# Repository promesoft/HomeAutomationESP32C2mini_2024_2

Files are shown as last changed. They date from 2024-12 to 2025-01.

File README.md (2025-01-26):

# HomeAutomationESP32C2mini_2024_2

 Kicad 8

# Purpose
Use for build into berker euro dåser

Two PSU modules and two uP modules

Additional power supply for +-12v and 5v for euro rack synth

## PSU
### 1 - Relay and 230V to 5v
### 2 - LED and 230V to 5v
## uP
### 1 - AM2320 and DS18B20
| ESP Designation  | Pin | Use |
| --- | --- | --- |
| U202 ESP32 C3 | GPIO05 | One Wire 18B20 |
| U202 ESP32 C3 | GPIO06 | SDA AM2320 / HDR |
| U202 ESP32 C3 | GPIO07 | SCL AM2320 / HDR |
| U202 ESP32 C3 | GPIO09 | LED |
| U202 ESP32 C3 | GPIO10 | Relay |
| U202 ESP32 C3 | GPIO21 | Relay Alternative |

### 2 - SSD1306 and AHT10
| ESP Designation  | Pin | Use |
| --- | --- | --- |
| U402 ESP32 C3 | GPIO05 | One Wire 18B20 |
| U402 ESP32 C3 | GPIO06 | SDA SSD1306 / AHT10 |
| U402 ESP32 C3 | GPIO07 | SCL SSD1306 / AHT10 |
| U402 ESP32 C3 | GPIO09 | LED |
| U402 ESP32 C3 | GPIO10 | Relay |
| U402 ESP32 C3 | GPIO21 | Relay Alternative |

## PSU for Euro rack - !!!!! EURORACK HEADER FLIPPED !!!!!!
+/-14v and 7v input

2x 16pin Eurorack power connectors as well as a +/-12v,5v,GND connector

Linear regulators 7805,7812,7912

Fuse blown detection with LED indication

# Status - Preliminary mounted
## Initial 
| Stage  | Detail | Status |
| --- | --- | --- |
| create material  | sch/pcb | OK  |
| | gerber | OK |
| production  | | OK |
|  | produced | OK |
|  | delivered | OK? |
## Preliminary validation
| Test  | Detail | Status |
| --- | --- | --- |
| Initial Inspection | PWR RLY | OK |
| Initial Inspection | PWR |  |
| Initial Inspection | ESP32C3 OLED| RELAY not working |
|  | | OLED 0,96" not pin-compatible |
| Initial Inspection | ESP32C3 |  |
| Initial Technical Test | PWR RLY+ESP32C3 OLED AHT10 | OK - Blue LED req 820R - 10K pullup removed as impl in ESP32 pullup |
| Initial Technical Test |  |  |
| Initial Technical Test |  |  |
| Initial Product Test | PWR RLY+ESP32C3 OLED AHT10 | OK |
| Initial Product Test |  |  |
| Initial Product Test |  |  |
| Power Draw |  |  |
| Power Draw |  |  |
| Power Draw |  |  |

## Secondary validation
| Test  | Detail | Status |
| --- | --- |--- |
| Product Test |  | |
| Product Test |  |  |
| Quality | | |
| Quality | | |
| Long Term Product Test |  |  |
| Power Draw |  |  |
| Power Draw |  |  |
| Power Draw |  |  |

## Errata
### Errata - Sub 1
### Errata - Sub 2
### Errata - Eurorack PSU - !!!!! EURORACK HEADER FLIPPED !!!!!!
| ERROR  | Detail | Workaround |
| --- | --- |--- |
| J601 and J602 flipped | -12v on PIN 15+16 - should have been PIN 1+2 | FLIP the header compared to the silkscreen |

## Issues and Notes
### Sub 1
### Sub 2

# Pictures
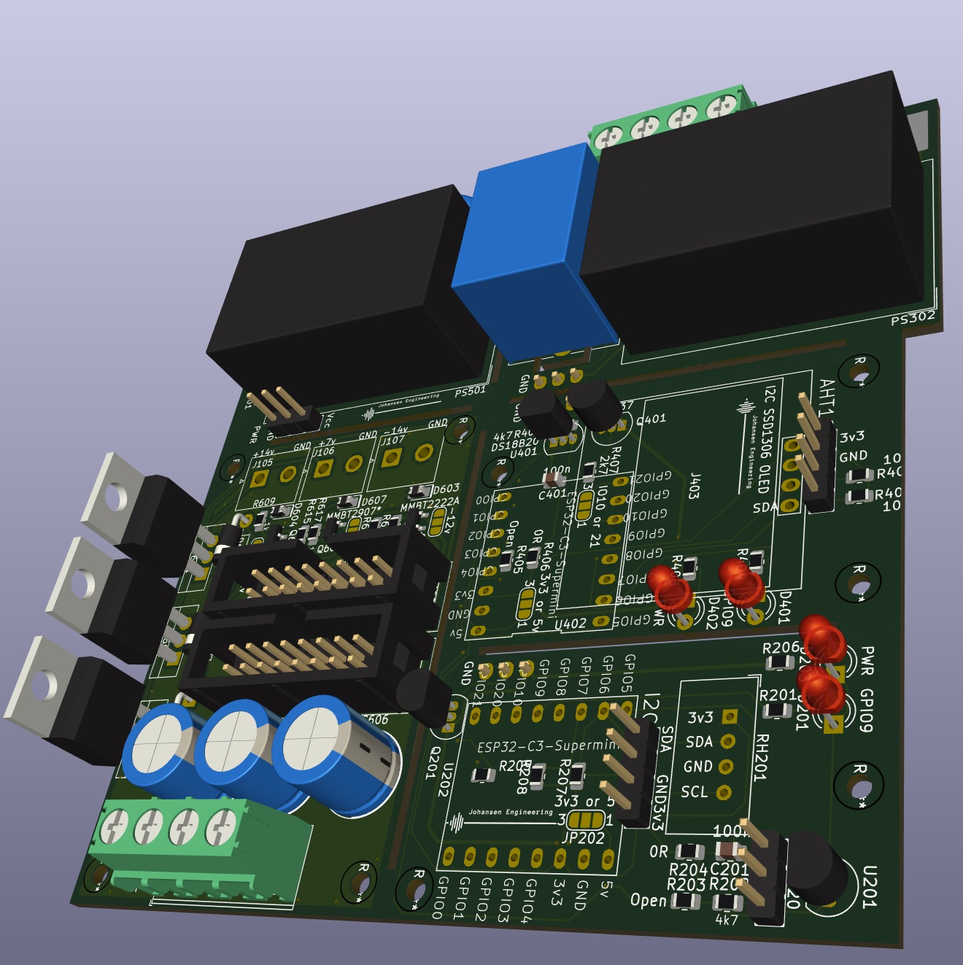
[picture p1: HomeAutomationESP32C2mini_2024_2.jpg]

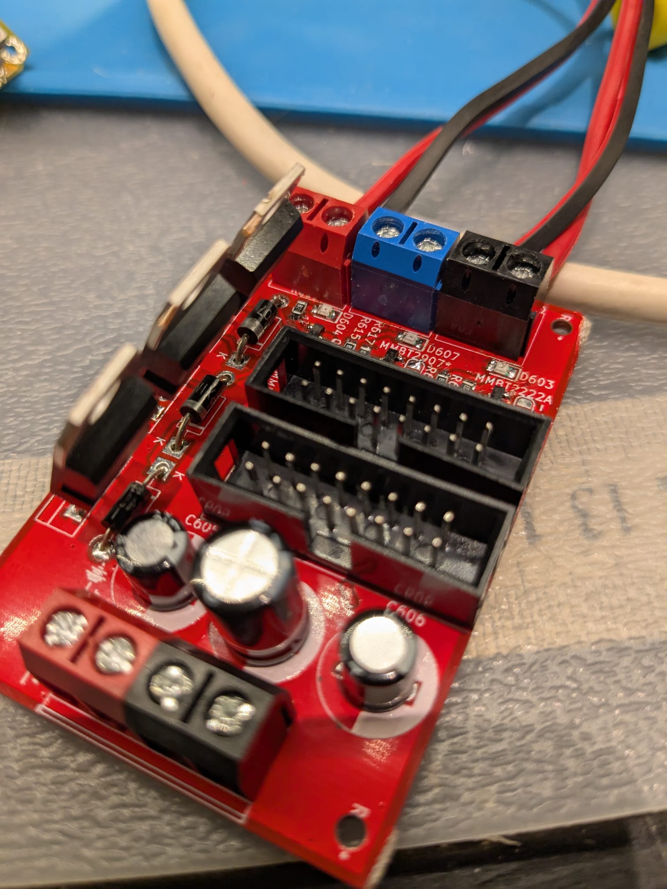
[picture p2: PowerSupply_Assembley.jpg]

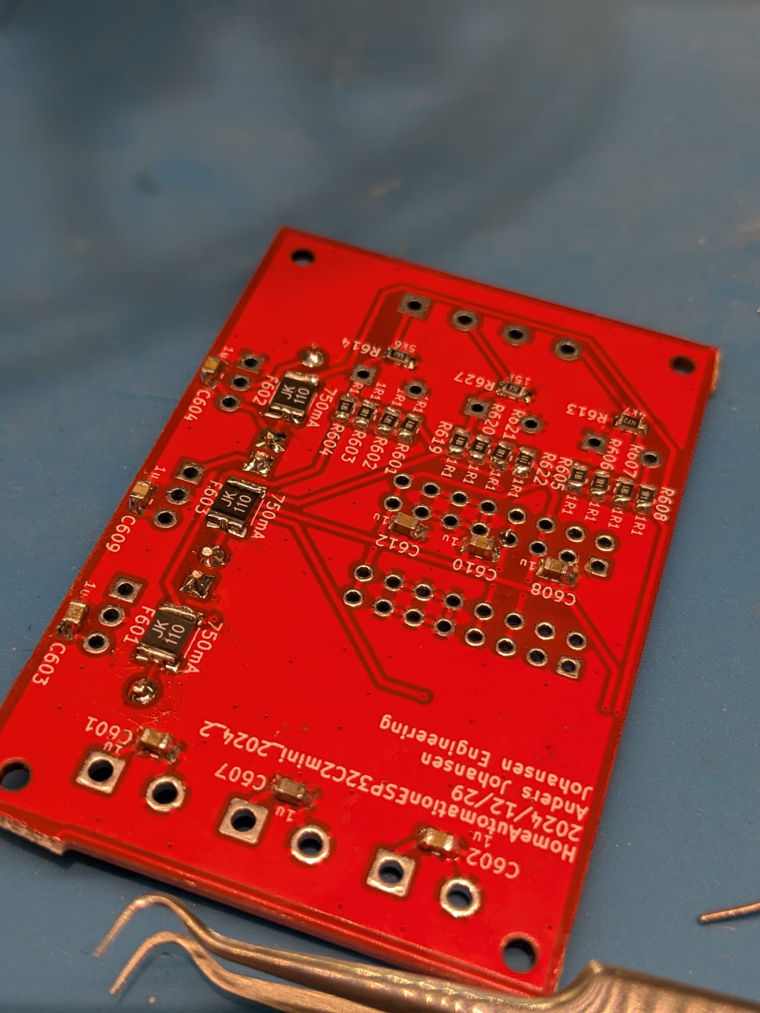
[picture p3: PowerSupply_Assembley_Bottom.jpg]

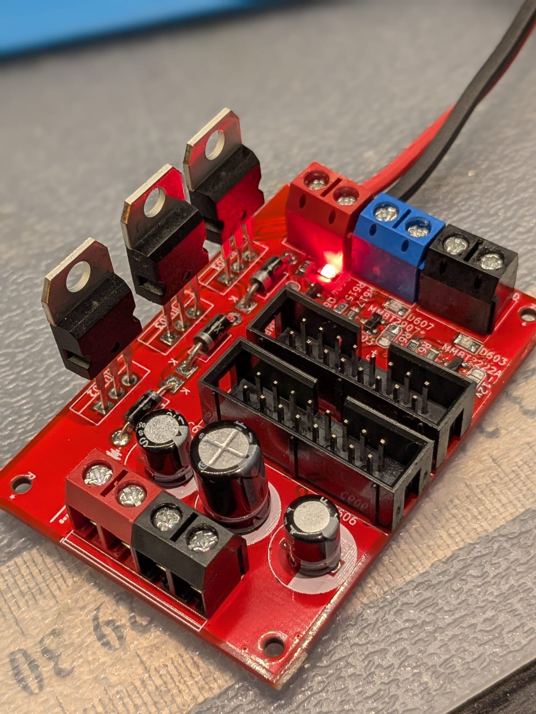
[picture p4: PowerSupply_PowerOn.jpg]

![]()
![]()

# Inspiration
https://github.com/pforrmi/KiCad-SSD1306-128x64/tree/master

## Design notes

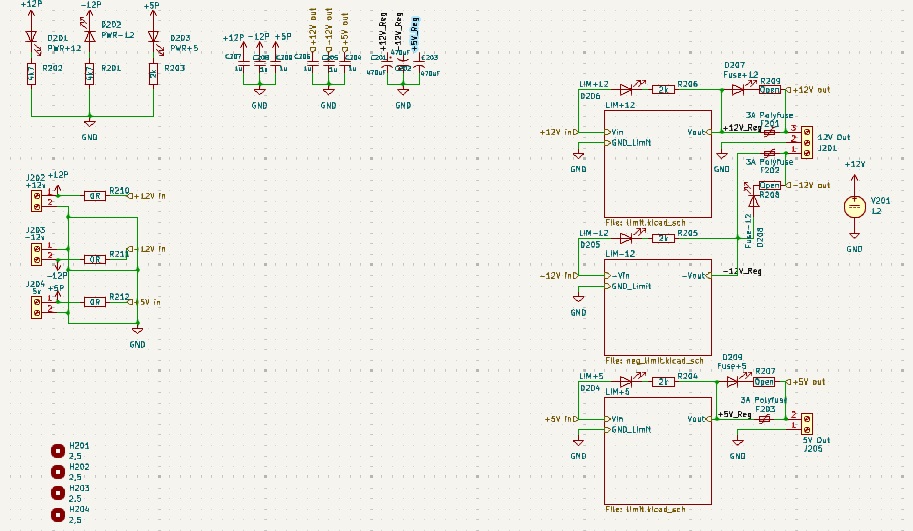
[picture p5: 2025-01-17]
Filter_sch_1.jpg

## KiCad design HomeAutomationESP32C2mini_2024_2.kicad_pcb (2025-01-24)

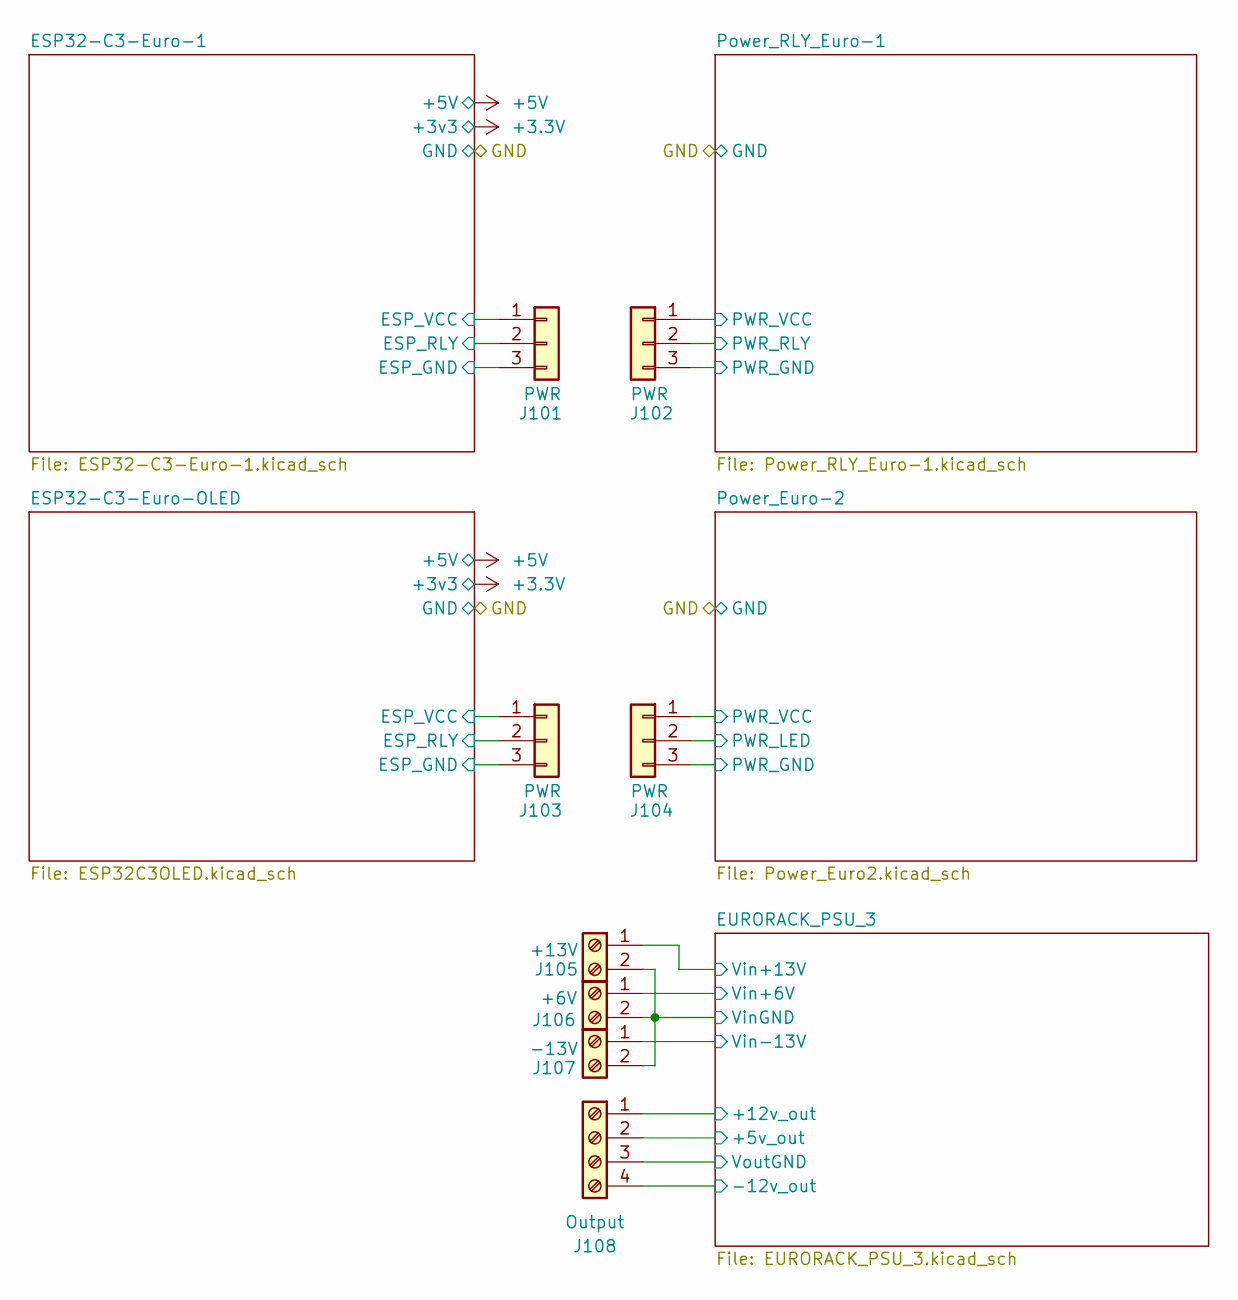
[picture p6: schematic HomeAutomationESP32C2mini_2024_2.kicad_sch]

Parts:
J101, J102, J103, J104: PWR; Pins_1x03_2.54mm_TH; Part Number 1-0301FBV0T
J105: +13V; JST_NV_B02P-NV_1x02_P5.00mm_Vertical
J106: +6V; JST_NV_B02P-NV_1x02_P5.00mm_Vertical
J107: -13V; JST_NV_B02P-NV_1x02_P5.00mm_Vertical
J108: Output; TerminalBlock_Phoenix_PT-1,5-4-5.0-H_1x04_P5.00mm_Horizontal

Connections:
/ESP32-C3-Euro-1/ESP_RLY: J101.2; also elsewhere on the board
/ESP32-C3-Euro-1/ESP_VCC: J101.1; also elsewhere on the board
/ESP32-C3-Euro-OLED/ESP_RLY: J103.2; also elsewhere on the board
/ESP32-C3-Euro-OLED/ESP_VCC: J103.1; also elsewhere on the board
/EURORACK_PSU_3/-12v_out: J108.4; also elsewhere on the board
/EURORACK_PSU_3/Vin+6V: J106.1; also elsewhere on the board
/EURORACK_PSU_3/Vin+13V: J105.1; also elsewhere on the board
/EURORACK_PSU_3/Vin-13V: J107.1; also elsewhere on the board
/GND: J101.3, J103.3, J104.3; also elsewhere on the board
/Power_Euro-2/PWR_LED: J104.2; also elsewhere on the board
/Power_Euro-2/PWR_VCC: J104.1; also elsewhere on the board
/Power_RLY_Euro-1/PWR_GND: J102.3; also elsewhere on the board
/Power_RLY_Euro-1/PWR_RLY: J102.2; also elsewhere on the board
/Power_RLY_Euro-1/PWR_VCC: J102.1; also elsewhere on the board

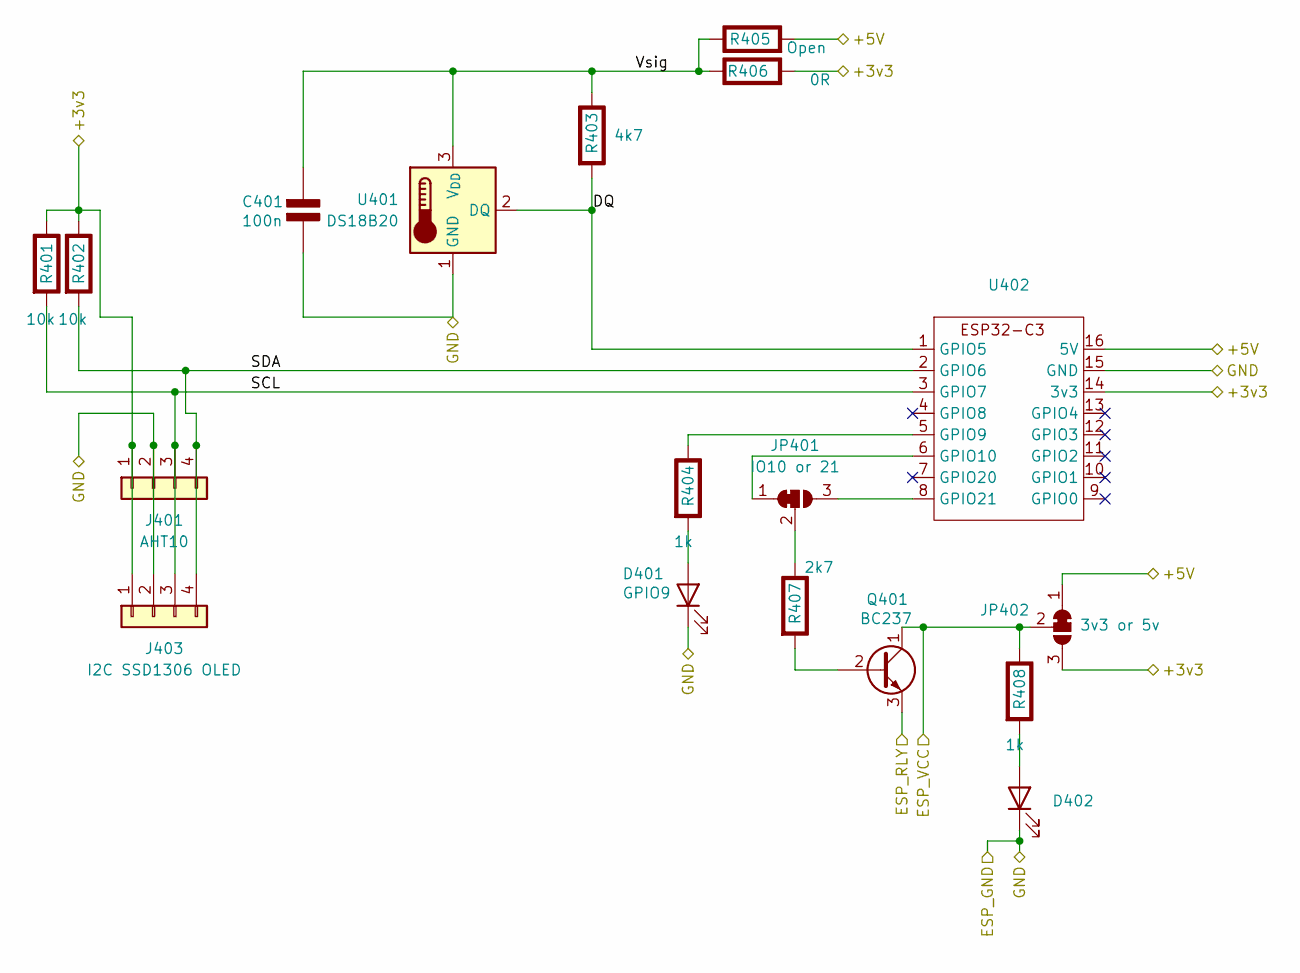
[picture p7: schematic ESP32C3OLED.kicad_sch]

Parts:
C401: 100n; C_0805_2012Metric; Rating V
D401: GPIO9; LED_D3.0mm
D402: PWR; LED_D3.0mm
J401: AHT10; Pins_1x04_2.54mm_TH
J403: I2C SSD1306 OLED; 128x64OLED
JP401: IO10 or 21; SolderJumper-3_P1.3mm_Bridged12_RoundedPad1.0x1.5mm_NumberL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
JP402: 3v3 or 5v; SolderJumper-3_P1.3mm_Bridged12_RoundedPad1.0x1.5mm_NumberL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
Q401: BC237; TO-92_Inline
R401, R402: 10k; R_0805_2012Metric; Rating W
R403: 4k7; R_0805_2012Metric; Rating W
R404, R408: 1k; R_0805_2012Metric; Rating W
R405: Open; R_0805_2012Metric; Rating W
R406: 0R; R_0805_2012Metric; Rating W
R407: 2k7; R_0805_2012Metric; Rating W
U401: DS18B20; TO-92_Inline
U402: ESP32-C3-Supermini

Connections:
+3.3V: J401.1, J403.1, JP402.3 (B), R401.1 (+), R402.1 (+), R406.2 (-), U402.14 (3v3); also elsewhere on the board
+5V: JP402.1 (A), R405.2 (-), U402.16 (5V); also elsewhere on the board
/ESP32-C3-Euro-OLED/DQ: R403.2 (-), U401.2 (DQ), U402.1 (GPIO5)
/ESP32-C3-Euro-OLED/ESP_RLY: Q401.3 (E); also elsewhere on the board
/ESP32-C3-Euro-OLED/ESP_VCC: JP402.2 (C), Q401.1 (C), R408.1 (+); also elsewhere on the board
/ESP32-C3-Euro-OLED/SCL: J401.3, J403.3, R401.2 (-), U402.3 (GPIO7)
/ESP32-C3-Euro-OLED/SDA: J401.4, J403.4, R402.2 (-), U402.2 (GPIO6)
/ESP32-C3-Euro-OLED/Vsig: C401.1 (+), R403.1 (+), R405.1 (+), R406.1 (+), U401.3 (V_{DD})
/GND: C401.2 (-), D401.1 (K), D402.1 (K), J401.2, J403.2, U401.1 (GND), U402.15 (GND); also elsewhere on the board
unnamed: D401.2 (A), R404.2 (-)
unnamed: D402.2 (A), R408.2 (-)
unnamed: JP401.1 (A), U402.6 (GPIO10)
unnamed: JP401.3 (B), U402.8 (GPIO21)
unnamed: JP401.2 (C), R407.1 (+)
unnamed: Q401.2 (B), R407.2 (-)
unnamed: R404.1 (+), U402.5 (GPIO9)

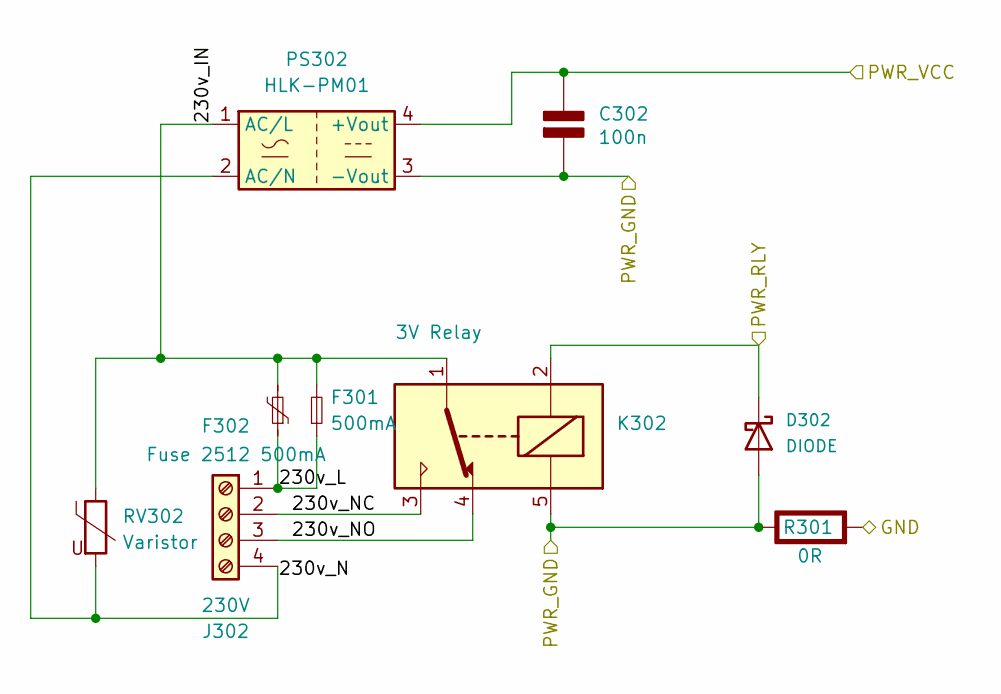
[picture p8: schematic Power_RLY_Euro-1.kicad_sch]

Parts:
C302: 100n; C_0805_2012Metric; Rating V
D302: DIODE; D_DO-41_SOD81_P10.16mm_Horizontal
F301: 500mA; Fuse_Littelfuse-NANO2-462
F302: Fuse 2512 500mA; Fuse_2512_6332Metric_Pad1.52x3.35mm_HandSolder
J302: 230V; TerminalBlock_Phoenix_PT-1,5-4-5.0-H_1x04_P5.00mm_Horizontal
K302: 3V Relay; Relay_SPDT_SANYOU_SRD_Series_Form_C
PS302: HLK-PM01; Converter_ACDC_Hi-Link_HLK-PMxx
R301: 0R; R_0805_2012Metric; Rating W
RV302: Varistor; RV_Disc_D9mm_W4.8mm_P5mm

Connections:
/GND: R301.2 (-); also elsewhere on the board
/Power_RLY_Euro-1/230v_IN: F301.2, F302.2, K302.1, PS302.1 (AC/L), RV302.1
/Power_RLY_Euro-1/230v_L: F301.1, F302.1, J302.1
/Power_RLY_Euro-1/230v_N: J302.4, PS302.2 (AC/N), RV302.2
/Power_RLY_Euro-1/230v_NC: J302.2, K302.3
/Power_RLY_Euro-1/230v_NO: J302.3, K302.4
/Power_RLY_Euro-1/PWR_GND: C302.2 (-), D302.2 (A), K302.5, PS302.3 (-Vout), R301.1 (+); also elsewhere on the board
/Power_RLY_Euro-1/PWR_RLY: D302.1 (K), K302.2; also elsewhere on the board
/Power_RLY_Euro-1/PWR_VCC: C302.1 (+), PS302.4 (+Vout); also elsewhere on the board

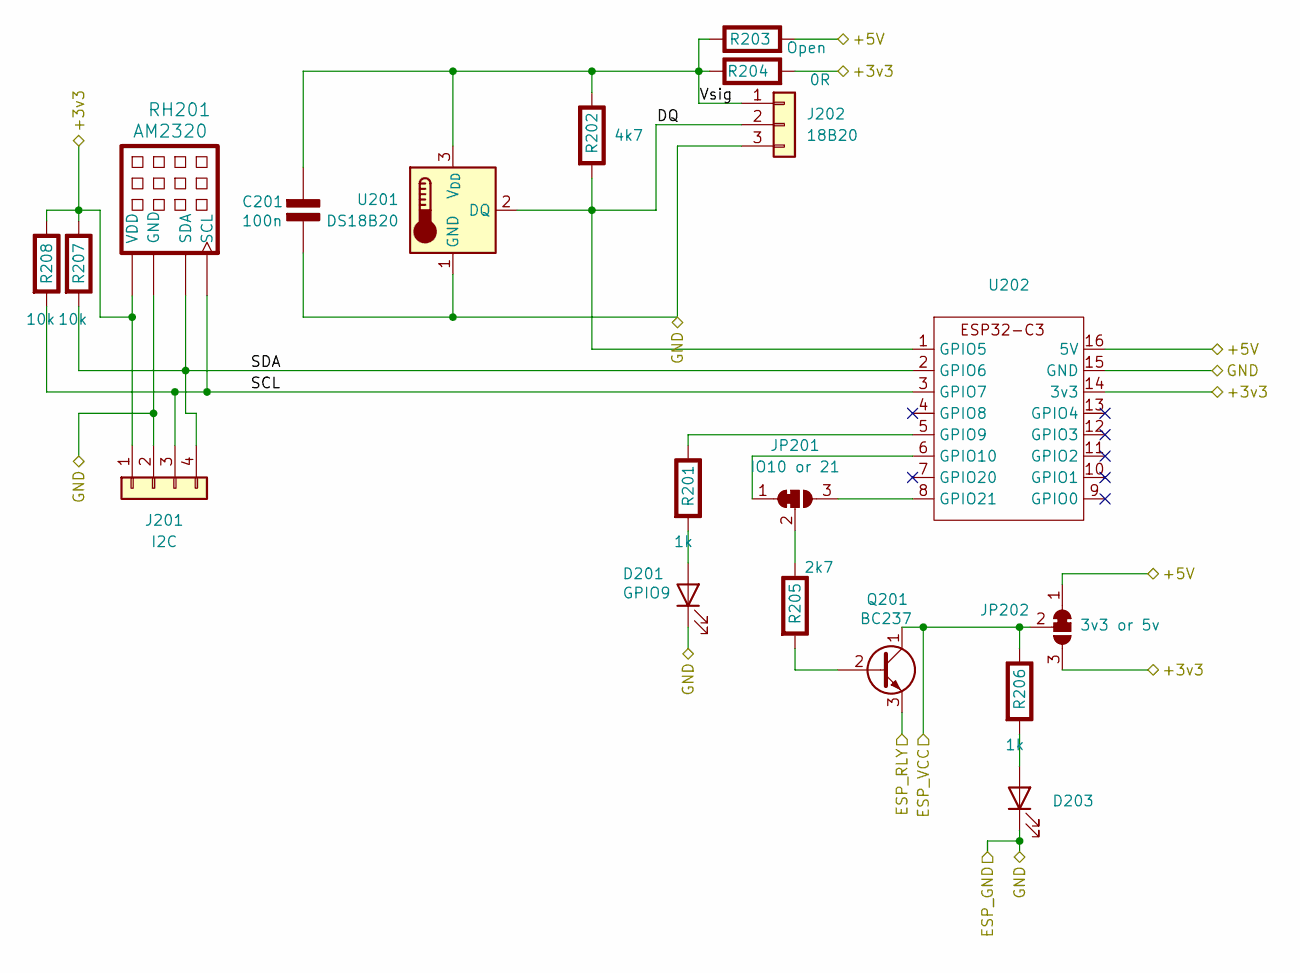
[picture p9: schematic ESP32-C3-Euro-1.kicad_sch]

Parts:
C201: 100n; C_0805_2012Metric; Rating V
D201: GPIO9; LED_D3.0mm
D203: PWR; LED_D3.0mm
J201: I2C; Pins_1x04_2.54mm_TH
J202: 18B20; Pins_1x03_2.54mm_TH; Part Number 1-0301FBV0T
JP201: IO10 or 21; SolderJumper-3_P1.3mm_Bridged12_RoundedPad1.0x1.5mm_NumberL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
JP202: 3v3 or 5v; SolderJumper-3_P1.3mm_Bridged12_RoundedPad1.0x1.5mm_NumberL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
Q201: BC237; TO-92_Inline
R201, R206: 1k; R_0805_2012Metric; Rating W
R202: 4k7; R_0805_2012Metric; Rating W
R203: Open; R_0805_2012Metric; Rating W
R204: 0R; R_0805_2012Metric; Rating W
R205: 2k7; R_0805_2012Metric; Rating W
R207, R208: 10k; R_0805_2012Metric; Rating W
RH201: AM2320; ASAIR_AM2302_P2.54mm_Vertical
U201: DS18B20; TO-92_Inline
U202: ESP32-C3-Supermini

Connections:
+3.3V: J201.1, JP202.3 (B), R204.2 (-), R207.1 (+), R208.1 (+), RH201.1 (VDD), U202.14 (3v3); also elsewhere on the board
+5V: JP202.1 (A), R203.2 (-), U202.16 (5V); also elsewhere on the board
/ESP32-C3-Euro-1/DQ: J202.2, R202.2 (-), U201.2 (DQ), U202.1 (GPIO5)
/ESP32-C3-Euro-1/ESP_RLY: Q201.3 (E); also elsewhere on the board
/ESP32-C3-Euro-1/ESP_VCC: JP202.2 (C), Q201.1 (C), R206.1 (+); also elsewhere on the board
/ESP32-C3-Euro-1/SCL: J201.3, R208.2 (-), RH201.4 (SCL), U202.3 (GPIO7)
/ESP32-C3-Euro-1/SDA: J201.4, R207.2 (-), RH201.2 (SDA), U202.2 (GPIO6)
/ESP32-C3-Euro-1/Vsig: C201.1 (+), J202.1, R202.1 (+), R203.1 (+), R204.1 (+), U201.3 (V_{DD})
/GND: C201.2 (-), D201.1 (K), D203.1 (K), J201.2, J202.3, RH201.3 (GND), U201.1 (GND), U202.15 (GND); also elsewhere on the board
unnamed: D201.2 (A), R201.2 (-)
unnamed: D203.2 (A), R206.2 (-)
unnamed: JP201.1 (A), U202.6 (GPIO10)
unnamed: JP201.3 (B), U202.8 (GPIO21)
unnamed: JP201.2 (C), R205.1 (+)
unnamed: Q201.2 (B), R205.2 (-)
unnamed: R201.1 (+), U202.5 (GPIO9)

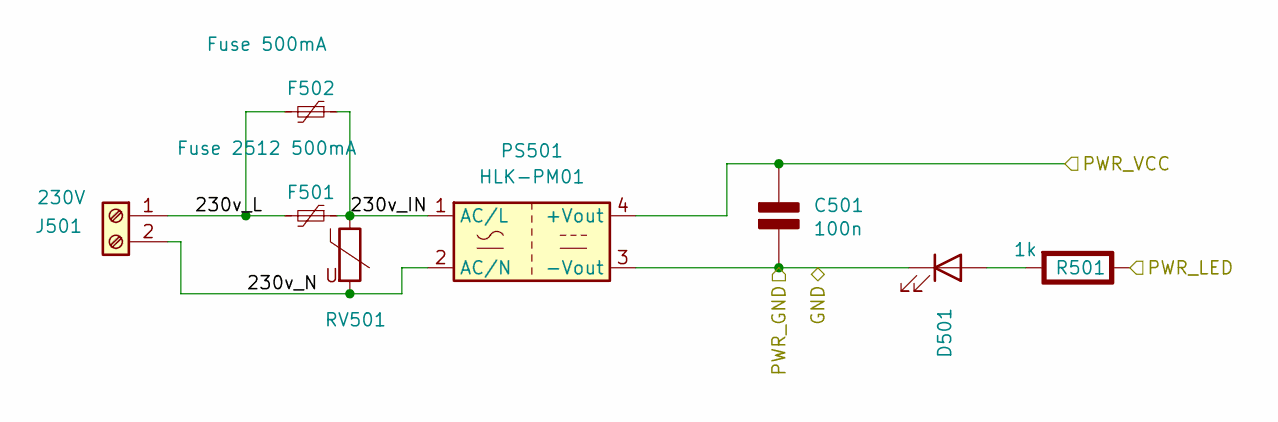
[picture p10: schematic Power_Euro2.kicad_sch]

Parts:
C501: 100n; C_0805_2012Metric; Rating V
D501: PWR; LED_0805_2012Metric_Pad1.15x1.40mm_HandSolder
F501: Fuse 2512 500mA; Fuse_2512_6332Metric_Pad1.52x3.35mm_HandSolder
F502: Fuse 500mA; L_Axial_L7.0mm_D3.3mm_P5.08mm_Vertical_Fastron_MICC
J501: 230V; JST_NV_B02P-NV_1x02_P5.00mm_Vertical
PS501: HLK-PM01; Converter_ACDC_Hi-Link_HLK-PMxx
R501: 1k; R_0805_2012Metric; Rating W
RV501: Varistor; RV_Disc_D9mm_W4.8mm_P5mm

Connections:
/GND: C501.2 (-), D501.1 (K), PS501.3 (-Vout); also elsewhere on the board
/Power_Euro-2/230v_IN: F501.1, F502.1, PS501.1 (AC/L), RV501.1
/Power_Euro-2/230v_L: F501.2, F502.2, J501.1
/Power_Euro-2/230v_N: J501.2, PS501.2 (AC/N), RV501.2
/Power_Euro-2/PWR_LED: R501.1 (+); also elsewhere on the board
/Power_Euro-2/PWR_VCC: C501.1 (+), PS501.4 (+Vout); also elsewhere on the board
unnamed: D501.2 (A), R501.2 (-)

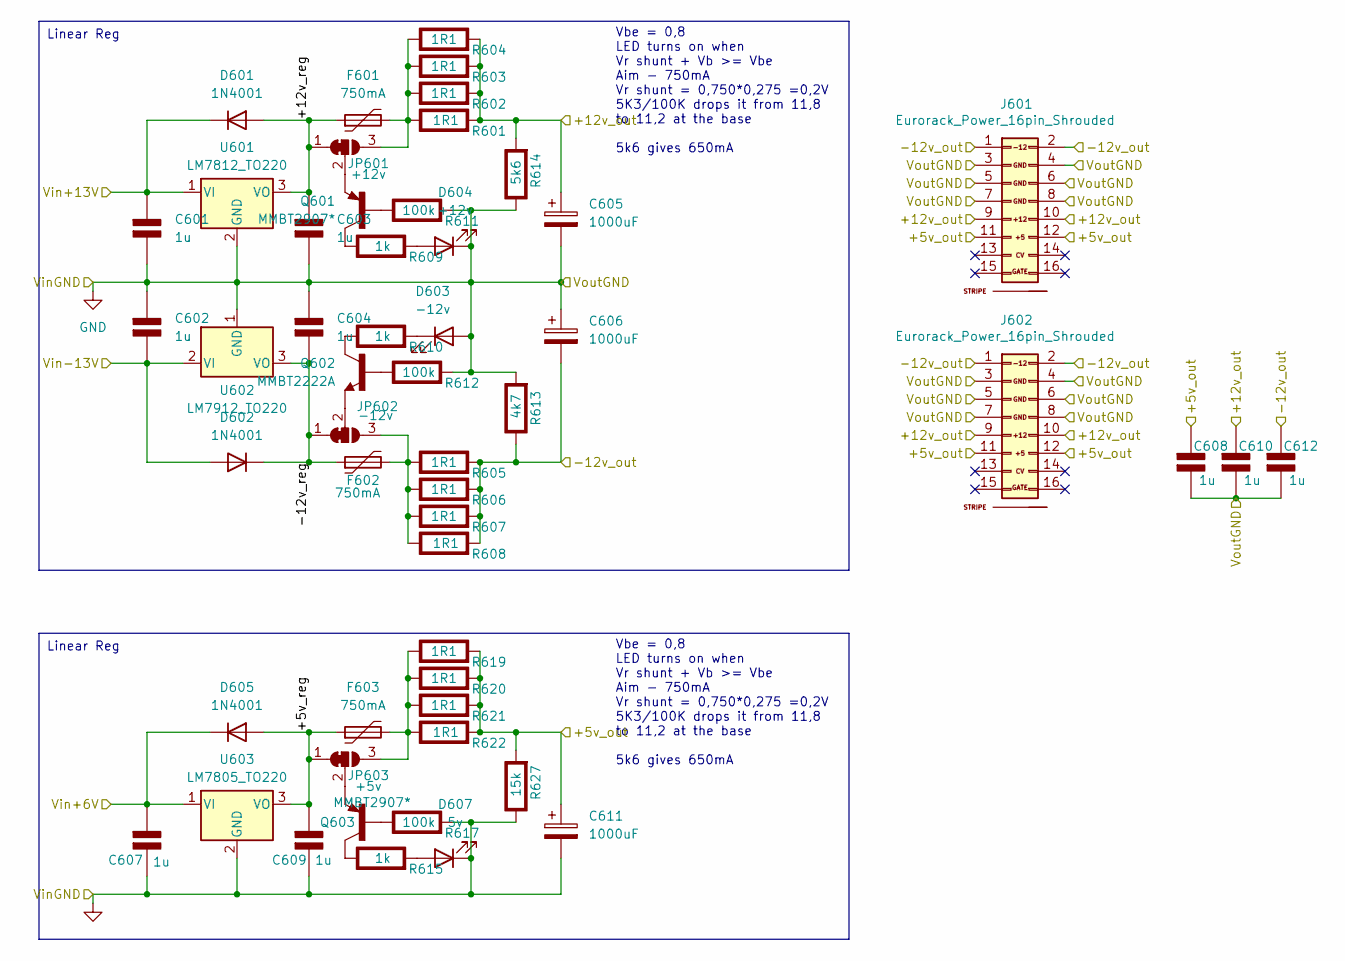
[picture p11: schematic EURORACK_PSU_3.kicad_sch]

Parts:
C601, C602, C603, C604, C607, C608, C609, C610, C612: 1u; C_0805_AJ; Rating V
C605, C606, C611: 1000uF; CP_Radial_D10.0mm_P5.00mm
D601, D602, D605: 1N4001; D_DO-41_SOD81_P10.16mm_Horizontal
D603: -12v; D_0805_AJ
D604: +12v; D_0805_AJ
D607: 5v; D_0805_AJ
F601, F602, F603: 750mA; Fuse_1812_4532Metric
J601, J602: Eurorack_Power_16pin_Shrouded; IDC-Header_2x08_P2.54mm_Vertical; Part Number LL1007-1 (2*8 HITEMP)
JP601: +12v; SolderJumper-3_P1.3mm_Bridged12_RoundedPad1.0x1.5mm_NumberL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
JP602: -12v; SolderJumper-3_P1.3mm_Bridged12_RoundedPad1.0x1.5mm_NumberL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
JP603: +5v; SolderJumper-3_P1.3mm_Bridged12_RoundedPad1.0x1.5mm_NumberL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
Q601, Q603: MMBT2907*; SOT-23
Q602: MMBT2222A; SOT-23
R601, R602, R603, R604, R605, R606, R607, R608, R619, R620, R621, R622: 1R1; R_0805_AJ; Rating W
R609, R610, R615: 1k; R_0805_AJ; Rating W
R611, R612, R617: 100k; R_0805_AJ; Rating W
R613: 4k7; R_0805_AJ; Rating W
R614: 5k6; R_0805_AJ; Rating W
R627: 15k; R_0805_AJ; Rating W
U601: LM7812_TO220; TO-220-3_Vertical
U602: LM7912_TO220; TO-220-3_Vertical
U603: LM7805_TO220; TO-220-3_Vertical

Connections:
/EURORACK_PSU_3/+5v_reg: C609.1 (+), D605.2 (A), F603.1, JP603.1 (A), U603.3 (VO)
/EURORACK_PSU_3/+12v_reg: C603.1 (+), D601.2 (A), F601.1, JP601.1 (A), U601.3 (VO)
/EURORACK_PSU_3/-12v_out: C606.2, C612.1 (+), J601.1, J601.2, J601.15 (-12V), J601.16, J602.1, J602.2, J602.15 (-12V), J602.16, R605.2 (-), R606.2 (-), R607.2 (-), R608.2 (-), R613.1 (+); also elsewhere on the board
/EURORACK_PSU_3/-12v_reg: C604.2 (-), D602.1 (K), F602.1, JP602.1 (A), U602.3 (VO)
/EURORACK_PSU_3/Vin+6V: C607.1 (+), D605.1 (K), U603.1 (VI); also elsewhere on the board
/EURORACK_PSU_3/Vin+13V: C601.1 (+), D601.1 (K), U601.1 (VI); also elsewhere on the board
/EURORACK_PSU_3/Vin-13V: C602.2 (-), D602.2 (A), U602.2 (VI); also elsewhere on the board
unnamed: D603.1 (K), R610.2 (-)
unnamed: D604.2 (A), R609.2 (-)
unnamed: D607.2 (A), R615.2 (-)
unnamed: F601.2, JP601.3 (B), R601.1 (+), R602.1 (+), R603.1 (+), R604.1 (+)
unnamed: JP601.2 (C), Q601.2 (E)
unnamed: F602.2, JP602.3 (B), R605.1 (+), R606.1 (+), R607.1 (+), R608.1 (+)
unnamed: JP602.2 (C), Q602.2 (E)
unnamed: F603.2, JP603.3 (B), R619.1 (+), R620.1 (+), R621.1 (+), R622.1 (+)
unnamed: JP603.2 (C), Q603.2 (E)
unnamed: Q601.1 (B), R611.1 (+)
unnamed: Q601.3 (C), R609.1 (+)
unnamed: Q602.1 (B), R612.1 (+)
unnamed: Q602.3 (C), R610.1 (+)
unnamed: Q603.1 (B), R617.1 (+)
unnamed: Q603.3 (C), R615.1 (+)

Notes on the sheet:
Linear Reg
Vbe = 0,8 LED turns on when Vr shunt + Vb >= Vbe Aim - 750mA Vr shunt = 0,750*0,275 =0,2V 5K3/100K drops it from 11,8 to 11,2 at the base 5k6 gives 650mA

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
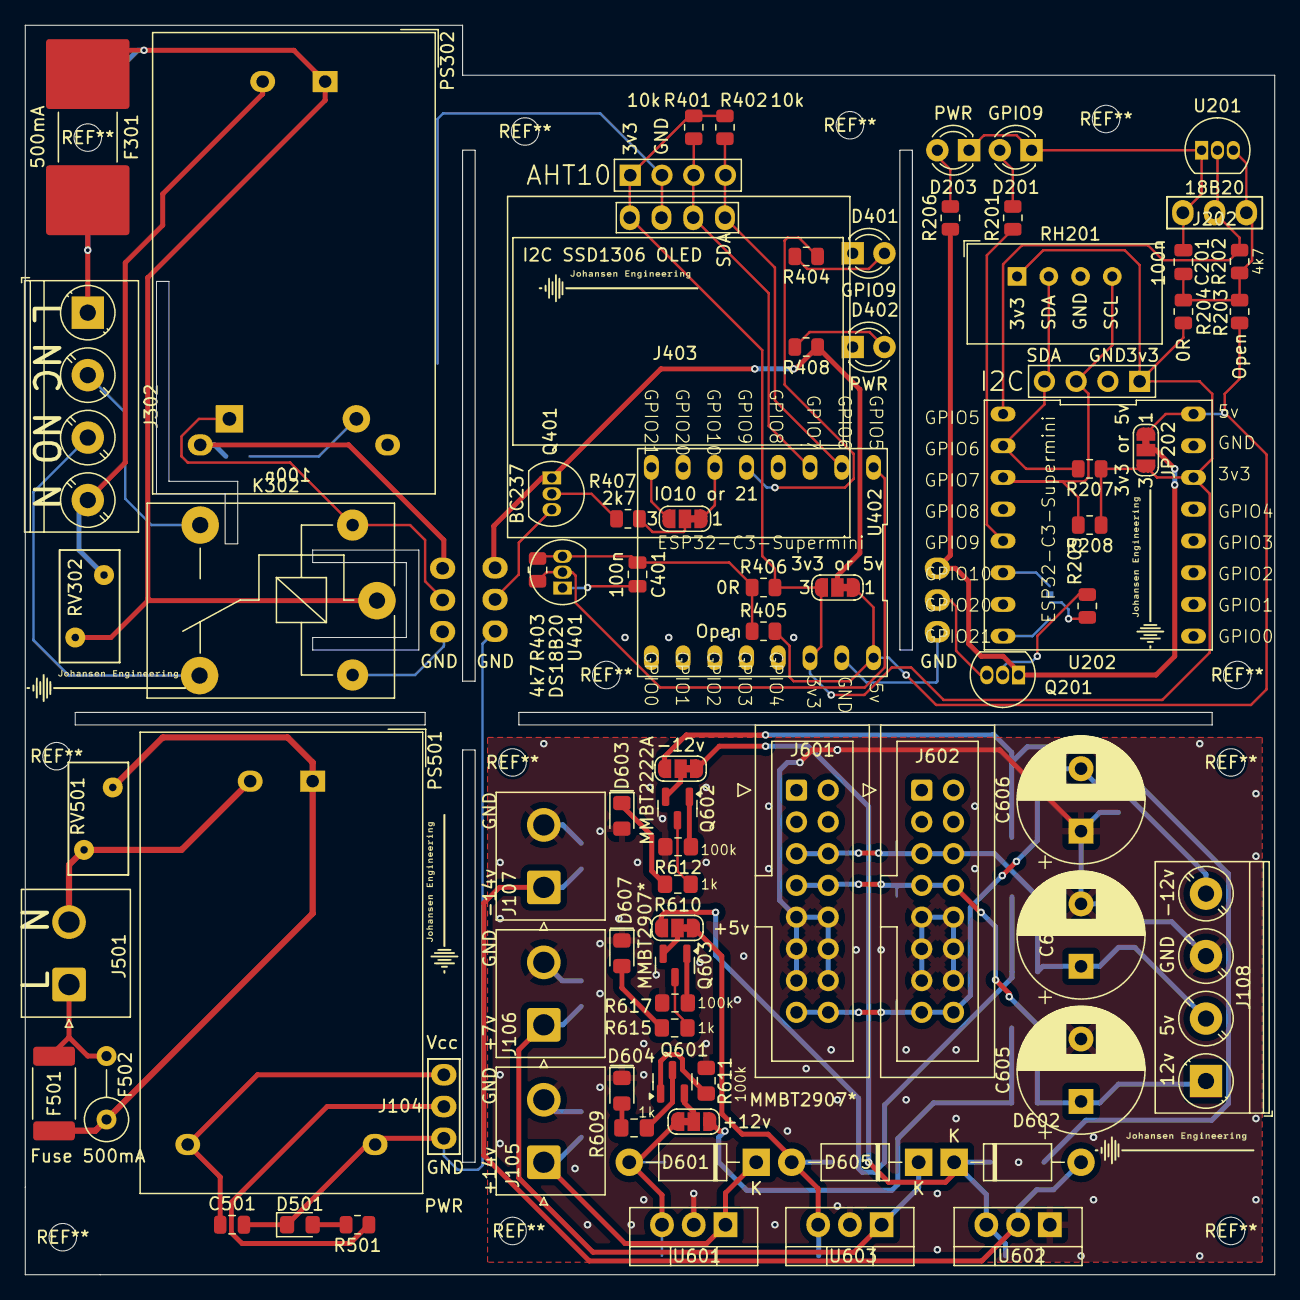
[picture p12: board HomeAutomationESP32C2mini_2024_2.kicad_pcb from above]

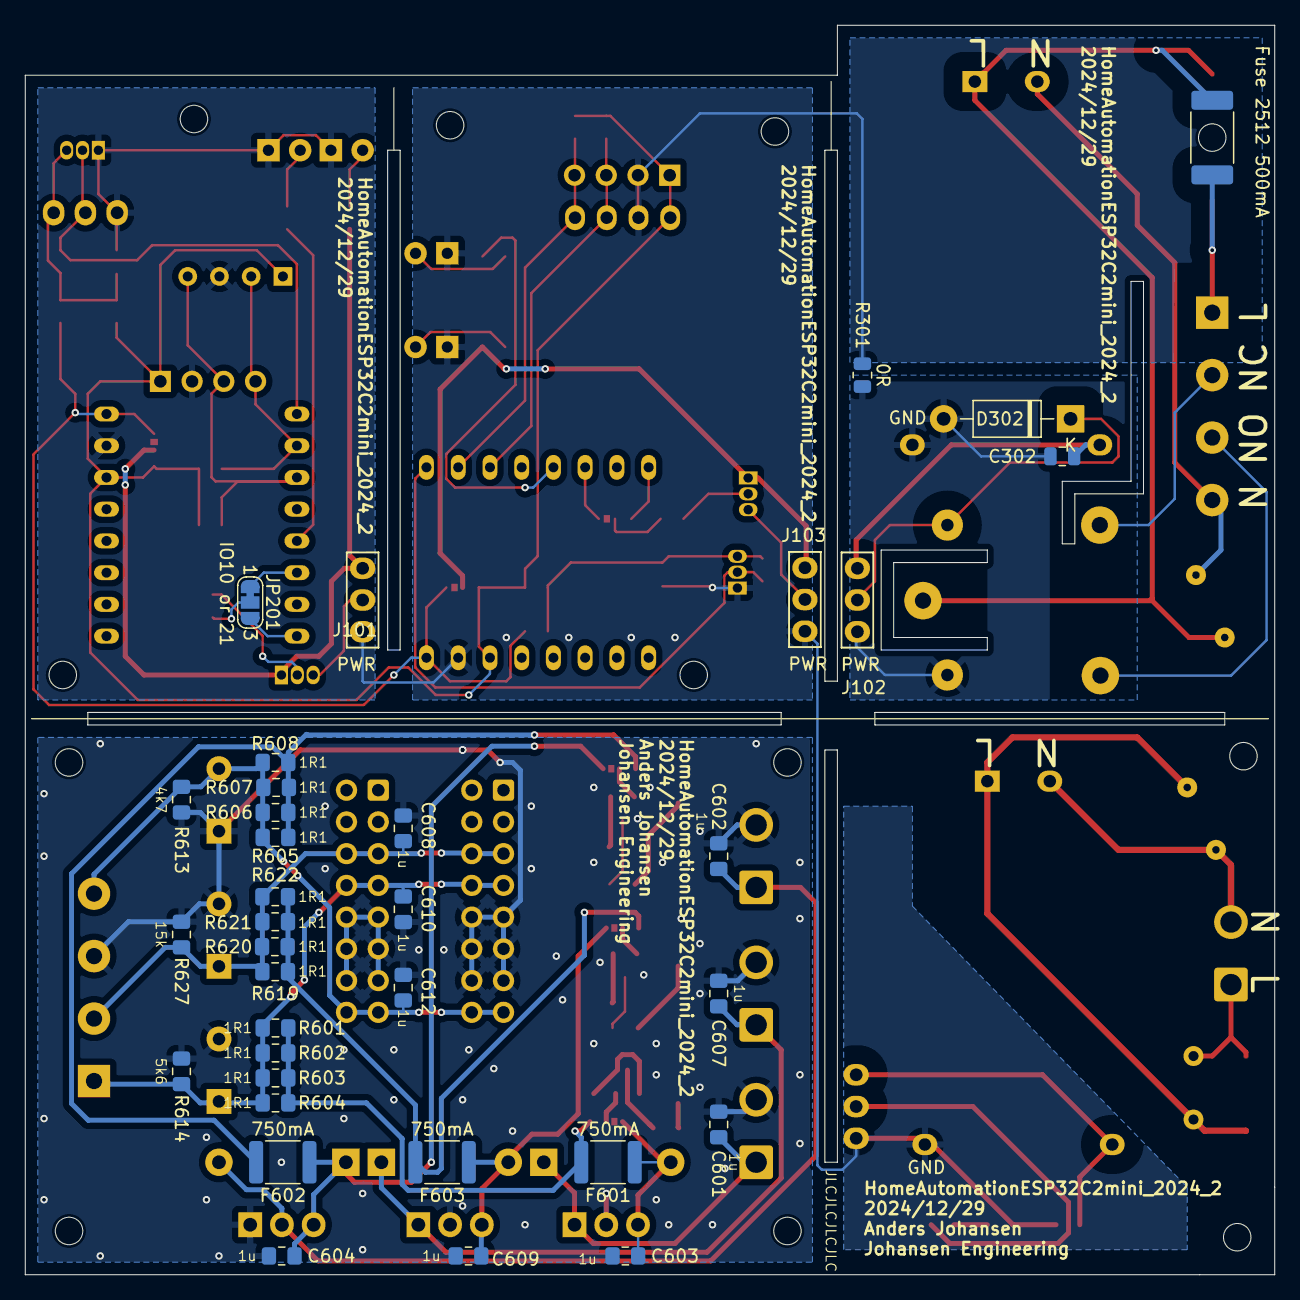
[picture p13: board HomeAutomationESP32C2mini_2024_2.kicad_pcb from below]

Board: 2 copper layers, 100.0 x 100.0 mm, 115 parts (35 on the bottom side), 68 nets.

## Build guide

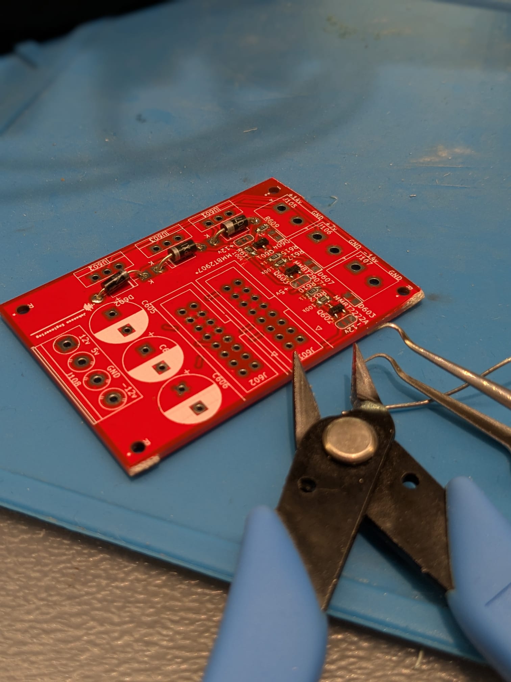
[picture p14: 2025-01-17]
PowerSupply_Assembley_Top.jpg

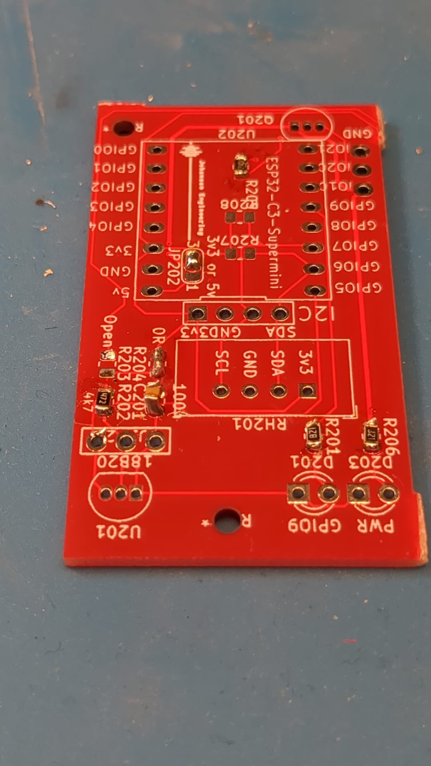
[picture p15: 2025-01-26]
ESP32C3_U202_Assembley_Top.jpg

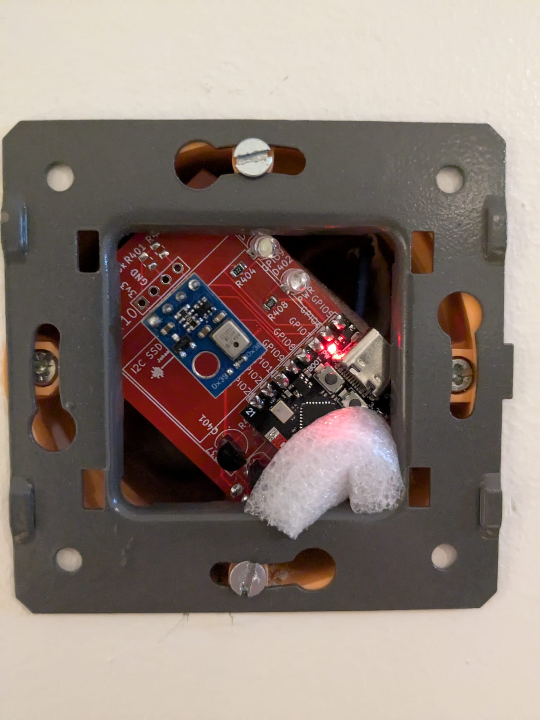
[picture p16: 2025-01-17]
ESP32C3_RLY_Install.jpg

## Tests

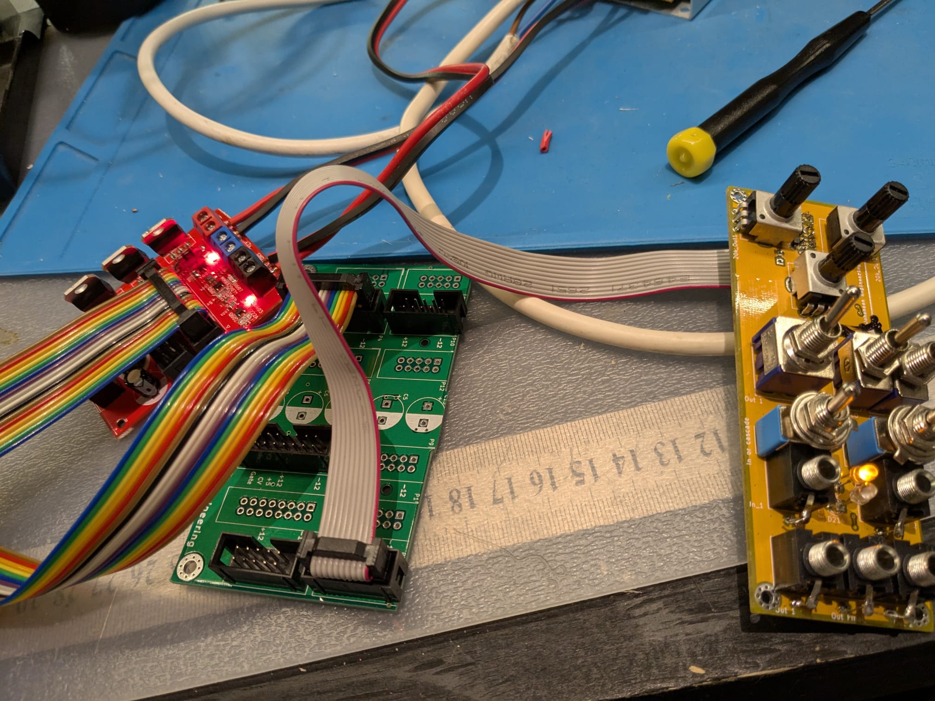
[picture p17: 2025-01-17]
PowerSupply_Test.jpg

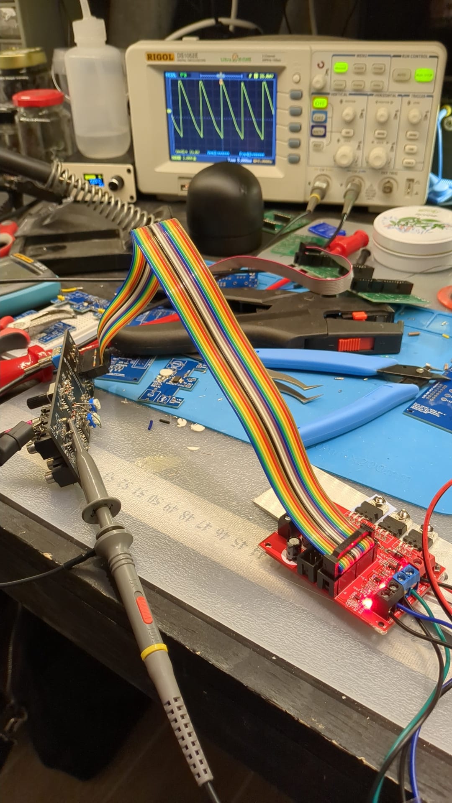
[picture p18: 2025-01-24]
PowerSupply_Test_VCO3.jpg
